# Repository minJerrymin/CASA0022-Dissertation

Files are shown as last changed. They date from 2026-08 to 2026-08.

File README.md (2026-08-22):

# Design and Deployment of a Solar-Powered LoRaWAN Air Quality Monitoring System

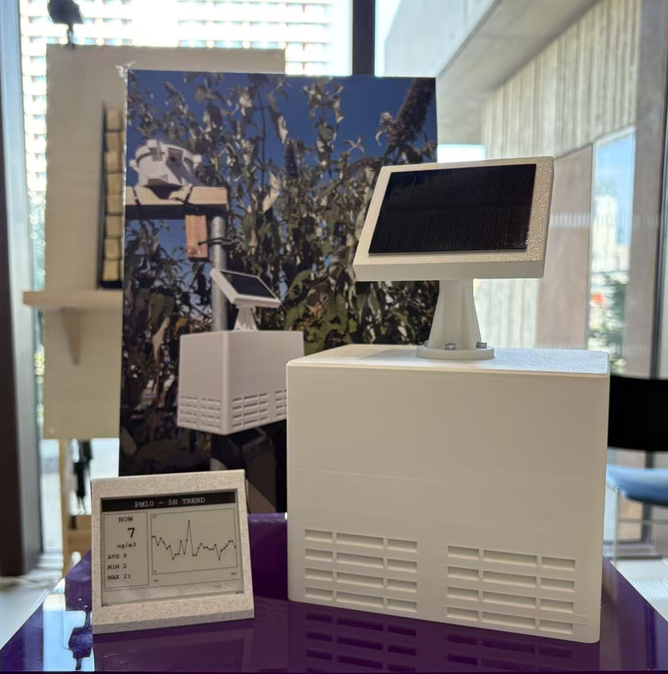
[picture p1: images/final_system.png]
Completed solar-powered sensing system


## Project overview

This project develops and deploys a solar-powered LoRaWAN air-quality sensing node to explore whether low-cost distributed sensing can contribute to denser urban monitoring where mains power is unavailable. It combines particulate and environmental sensing, low-power operation, cloud data storage and an indoor e-paper display.

The prototype demonstrates conditional viability rather than reference-grade performance. Its operation depends on adequate LoRaWAN coverage and available solar energy, and the external comparison sites were not co-located with the sensing node.

## System architecture

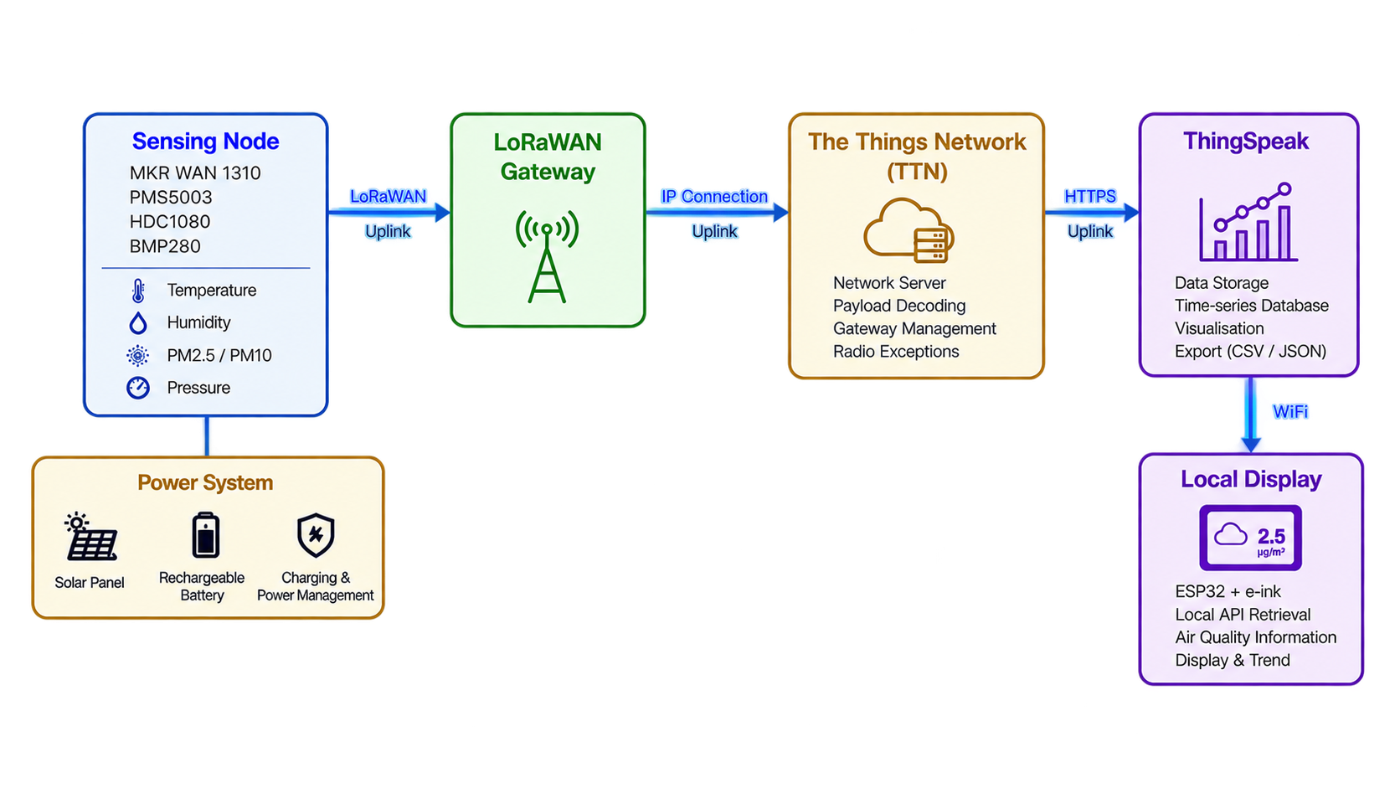
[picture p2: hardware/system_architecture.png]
Final system architecture and data pathway


The deployed data pathway is:

**Sensing node → LoRaWAN gateway → The Things Network (TTN) → ThingSpeak → Wi-Fi → local ESP32 + e-paper display**

The solar-powered outdoor node sends unconfirmed LoRaWAN uplinks through a gateway to The Things Network. Decoded measurements are forwarded to ThingSpeak. The indoor display separately retrieves the ThingSpeak channel over Wi-Fi; it does not receive data directly from TTN.

## Hardware

The sensing node uses an Arduino MKR WAN 1310 with an HDC1080, BMP280 and Plantower PMS5003. A 1 W solar panel and three-cell 3.6 V nominal NiMH battery pack connect through the Battery Charging Board, whose LOAD/OUTPUT supplies the MKR battery connector. MKR VIN is not used.

The MKR 3.3 V rail powers the HDC1080, BMP280 and Pololu S7V7F5 input. The Pololu output supplies 5 V to the PMS5003; MKR D5 controls SHDN. Two 100 µF capacitors stabilise the regulator input and output rails. All grounds are common.

The final physical UART arrangement is intentional: **MKR TX1 → PMS TX** and **MKR RX1 → PMS RX**.

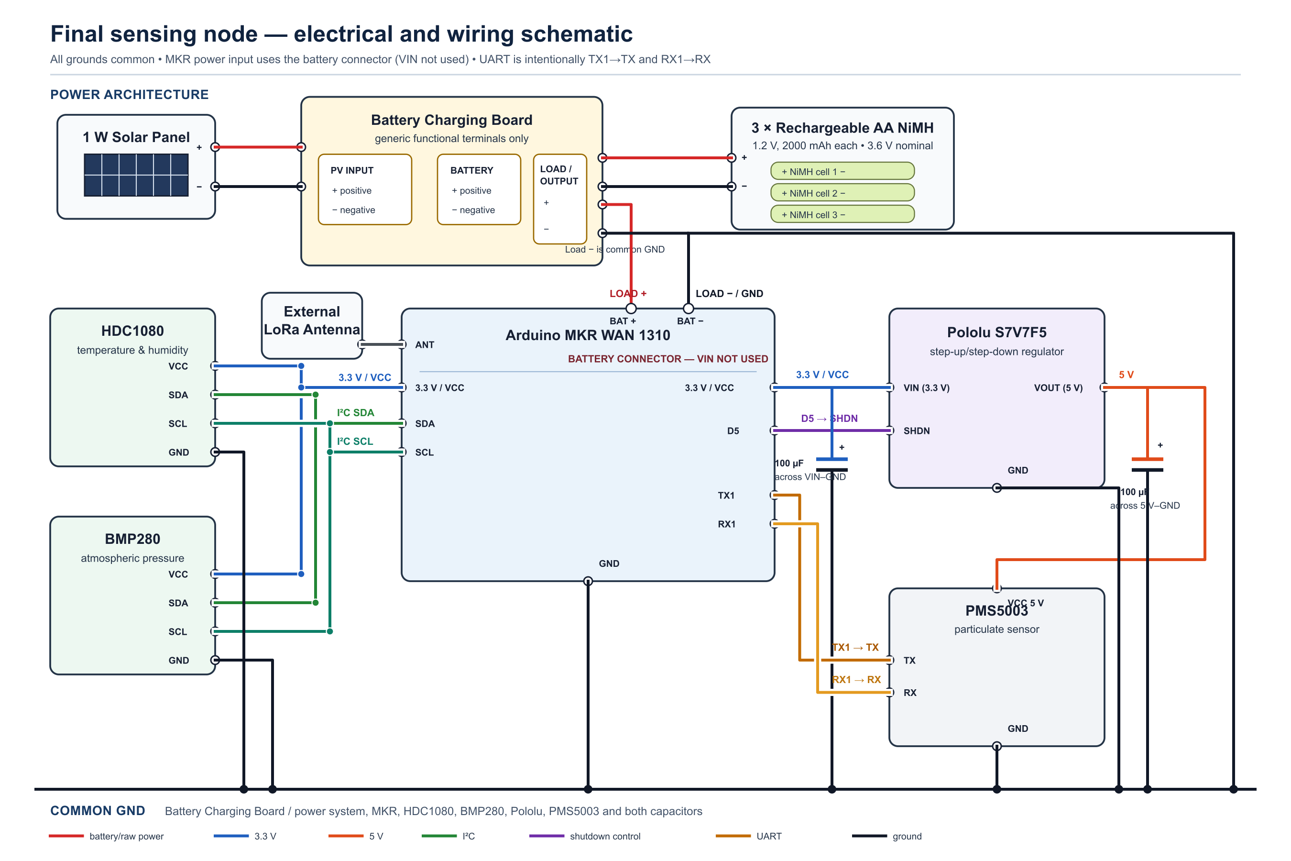
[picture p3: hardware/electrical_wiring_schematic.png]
Detailed electrical wiring schematic


See the concise [bill of materials](hardware/BOM.md).

## Firmware

- [`firmware/sensing_node/`](firmware/sensing_node/) — deployed MKR WAN 1310 sensing-node firmware.
- [`firmware/display/`](firmware/display/) — deployed FireBeetle 2 ESP32-E e-paper display firmware.
- [`firmware/diagnostics/`](firmware/diagnostics/) — standalone PMS5003 diagnostic utility, **not** the deployed sensing-node firmware.

Real TTN, Wi-Fi and ThingSpeak credentials are not included. For each deployed sketch, copy `arduino_secrets.example.h` to `arduino_secrets.h`, replace the placeholders locally, and keep that local file untracked.

The display firmware retains `WiFiClientSecure.setInsecure()` to reproduce the prototype. This disables TLS certificate verification and is a known prototype security limitation; a production deployment should validate the server certificate.

## LoRaWAN payload

The MKR WAN 1310 uses OTAA in the EU868 region and sends an unconfirmed 10-byte uplink on FPort 2.

| Bytes | Measurement | Encoding |
|---:|---|---|
| 0–1 | Temperature | signed int16, °C × 100 |
| 2–3 | Relative humidity | uint16, % × 100 |
| 4–5 | PM2.5 | uint16, µg/m³ |
| 6–7 | PM10 | uint16, µg/m³ |
| 8–9 | Atmospheric pressure | uint16, hPa × 10 |

Invalid PMS readings use the uint16 sentinel `65535`. The matching [TTN uplink decoder](ttn/uplink_decoder.js) exposes both descriptive names and ThingSpeak `field1`–`field5` values; it does not add a payload flag.

## Power management

Each cycle is 10 minutes. The PMS5003/regulator branch is enabled for a 30-second sensor warm-up and switched off during sleep. The measured whole-system active current was approximately 89.6 mA for an active period of about 37–40 seconds; sleep current was approximately 137 µA. This gives an estimated cycle-average current of approximately 6.13 mA.

These measurements support the feasibility of the low-power approach, but they do not establish guaranteed year-round solar autonomy.

## Deployment

The system was deployed at the UCL One Pool Street Roof Garden.

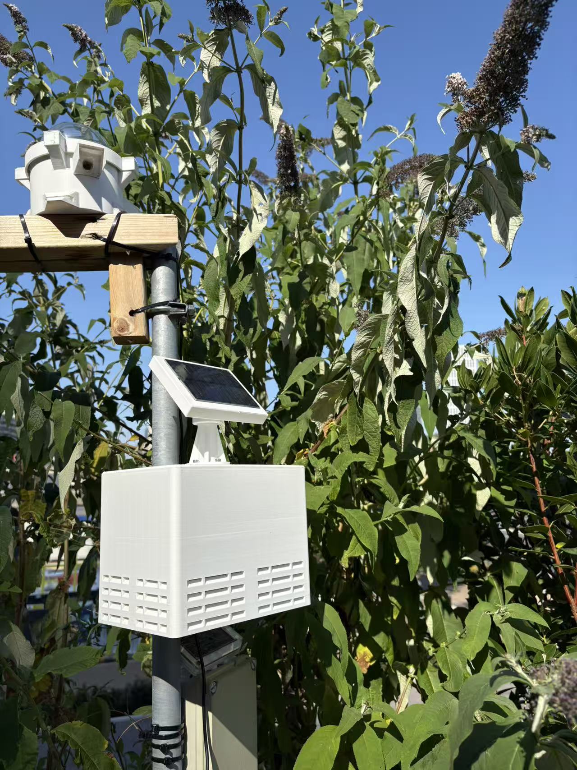
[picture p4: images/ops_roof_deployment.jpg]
Sensing node deployed at the UCL One Pool Street Roof Garden


## Evaluation and results

- ThingSpeak contains 4,961 complete records over a 38.42-day monitoring span. The median interval was 10.00 minutes, 98.79% of intervals were between 9.5 and 10.5 minutes, and the longest continuous period without a gap over one hour was approximately 34.66 days. Four early long gaps occurred during debugging, power-off and system reconfiguration, before the stable deployment period.
- The final TTN export contains 318 uplinks over approximately 2.21 days, with a 10.00-minute median interval, one absent frame counter and 994 total gateway receptions.
- Temporal comparison showed strong agreement for temperature, relative humidity and pressure; PM2.5 agreement was moderate and PM10 agreement was weak.
- The PMS5003 reported identical PM2.5 and PM10 values in 4,903 of 4,961 records (98.83%), an important limitation of this prototype dataset.

Because the Weather Underground and London Air Quality Network stations were not co-located with the project node, these results are temporal comparisons rather than formal calibration. They do not demonstrate reference-grade accuracy or validated PM10 performance.

## E-paper display

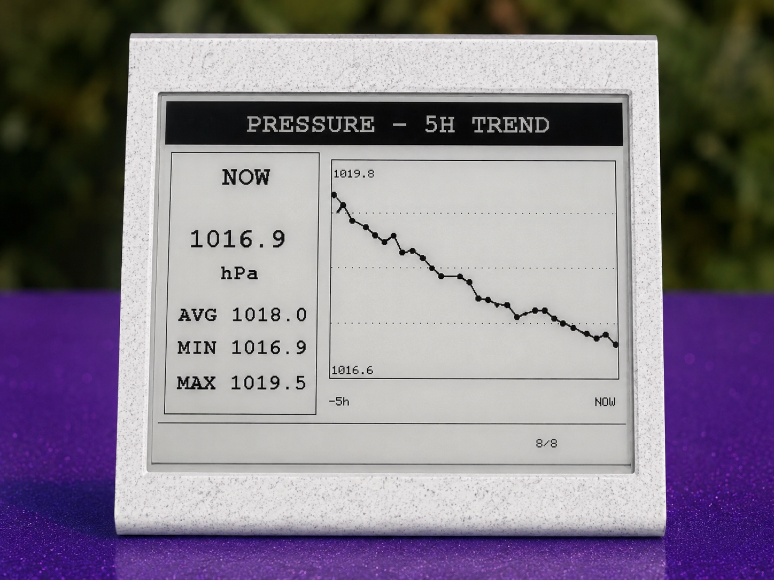
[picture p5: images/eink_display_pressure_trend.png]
Pressure five-hour trend on page 8 of the e-paper display


The indoor FireBeetle 2 ESP32-E display retrieves the latest ThingSpeak entry approximately every 60 seconds. When a new entry is detected it downloads 30 ten-minute samples, providing approximately five hours of history. Eight pages are shown for 20 seconds each (160 seconds per carousel); after three complete cycles, the firmware returns to a full-refresh summary page.

## CAD

The repository includes the author's editable Fusion 360 source and printable STL for the [indoor display enclosure](hardware/cad/display_enclosure/). These files are not sensing-node enclosure CAD.

The outdoor sensing enclosure's concept and functional requirements were developed through discussion involving the project author and Simon. Simon completed the detailed CAD design and 3D printing; his sensing-enclosure CAD is not published here.

## Data and analysis

- [Data documentation](data/README.md)
- [Analysis method and reproduction instructions](analysis/README.md)

The final ThingSpeak observations and metadata-minimised TTN analytical CSV are public. Raw Weather Underground and LAQN comparison files remain local because redistribution rights have not been assumed.

## Repository structure

```text
.
├── analysis/                  # Reproducible final calculations
├── data/                      # Public project and clean TTN data
├── firmware/
│   ├── sensing_node/          # Deployed outdoor-node firmware
│   ├── display/               # Deployed e-paper firmware
│   └── diagnostics/           # PMS5003 diagnostic utility
├── hardware/
│   └── cad/display_enclosure/ # Author's indoor-display CAD
├── images/                    # Selected final project images
├── ttn/                       # 10-byte uplink decoder
├── index.html                 # GitHub Pages exhibition page
└── README.md
```

## Dissertation context

This repository accompanies the CASA0022 MSc Connected Environments dissertation at University College London. It provides the technical implementation, selected data and reproducible final analysis; the dissertation PDF is not included.

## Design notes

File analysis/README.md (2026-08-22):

# Final analysis

`final_analysis.py` reconstructs the final Chapter 4 calculations from the supplied project data and local comparison inputs. It calculates each result from the observations; dissertation target values are used only for the printed validation comparison.

## Requirements

- Python 3.10 or later
- Packages listed in `requirements.txt` (`pandas` and `numpy`)

Install and run from the repository root:

```bash
python -m pip install -r analysis/requirements.txt
python analysis/final_analysis.py
```

To regenerate the public TTN analytical CSV from the local raw export:

```bash
python analysis/final_analysis.py --write-clean-ttn
```

## Inputs

| Input | Default path | Public? | Purpose |
|---|---|---:|---|
| Project sensing data | `data/project_sensing_data.csv` | Yes | Operational statistics, hourly project means and PMS consistency |
| Clean TTN data | `data/ttn_uplinks_clean.csv` | Yes | Public fallback for TTN statistics |
| Raw TTN export | `../ttn_uplinks_30days.jsonl` | No | Local regeneration of the clean TTN CSV |
| Weather Underground JSON | `../wunderground_20260801_20260816.json` | No | Temperature, humidity and pressure comparison |
| LAQN CSV | `../Londonair PM DATA.csv` | No | PM2.5 and PM10 comparison |

The three local-only paths assume the supplied source files remain beside the repository. Command-line options can point to equivalent files elsewhere. If the external comparison files are absent, the script still runs the operational, TTN and PMS consistency analyses and reports that the comparisons were skipped.

## Method

ThingSpeak `created_at` values and TTN timestamps are parsed as UTC and sorted chronologically. Consecutive intervals are calculated directly. A stable segment ends whenever the next interval exceeds one hour; the longest segment is the largest elapsed time between its first and last records.

For external comparisons, project observations are converted from UTC to `Europe/London`, floored to the local hour and averaged. Weather Underground observations use the supplied `obsTimeLocal` hour for station ILONDO932. Temperature uses `tempAvg`, humidity uses `humidityAvg`, and pressure is `(pressureMax + pressureMin) / 2`.

LAQN `ReadingDateTime` is parsed day-first as local clock time. Hourly project PM means are matched by local hour to site TH5 (Tower Hamlets, Victoria Park). Missing external values are excluded pairwise, which produces 791 PM2.5 pairs and 779 PM10 pairs in the supplied files.

Pearson's `r` is calculated from each matched pair of numeric series. Mean difference always means `project − external source`. The sites were not co-located, so these are temporal comparisons rather than a formal calibration.

## Outputs

The script prints a concise `metric | reproduced | expected | status` table. `PASS` means the reconstructed value falls within a small, explicitly defined rounding tolerance; `INFO` identifies a useful metric for which the dissertation specification did not state an expected value.

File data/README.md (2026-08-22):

# Data

## `project_sensing_data.csv`

This is the final sensing dataset exported from the project's ThingSpeak channel. It contains 4,961 records from 9 July to 17 August 2026. All five measurement fields are populated in every record.

| Column | Measurement | Unit |
|---|---|---|
| `field1` | Temperature | °C |
| `field2` | Relative humidity | % |
| `field3` | PM2.5 | µg/m³ |
| `field4` | PM10 | µg/m³ |
| `field5` | Atmospheric pressure | hPa |

The observations are unchanged from the final export; only the filename has been made descriptive.

## `ttn_uplinks_clean.csv`

This public analytical dataset contains 318 final TTN uplinks from approximately 15–17 August 2026. It retains the timestamp, frame counter, FPort, decoded measurements and number of gateway receptions for each uplink.

The local raw JSONL export was not published. Device and application identifiers, EUIs and addresses, gateway identifiers and locations, radio metadata, correlation identifiers, raw binary payloads and other network metadata were removed because they are unnecessary for the reported analysis.

## External comparison data

Raw third-party files are intentionally not redistributed. To reproduce the complete comparison, obtain equivalent exports in the formats described in [the analysis documentation](../analysis/README.md):

- Weather Underground personal weather station ILONDO932, 1–16 August 2026, for temperature, relative humidity and pressure.
- London Air Quality Network site TH5 — Tower Hamlets, Victoria Park, for PM2.5 and PM10.

These external sites were not co-located with the project sensing node. The comparison therefore assesses temporal agreement rather than formal sensor calibration.

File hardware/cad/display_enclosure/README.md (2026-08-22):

# Indoor display enclosure

These files are the author's enclosure design for the indoor e-paper display, created in Autodesk Fusion 360 for the DFRobot FireBeetle 2 ESP32-E and 4.2-inch e-paper display.

- `display_enclosure.f3d` is the editable Fusion 360 source.
- `display_enclosure.stl` is the printable export.

This is not the outdoor sensing-node enclosure. The sensing enclosure's concept and functional requirements were developed through discussion involving the project author and Simon; Simon completed its detailed CAD design and 3D printing. Simon's CAD files are not included here.

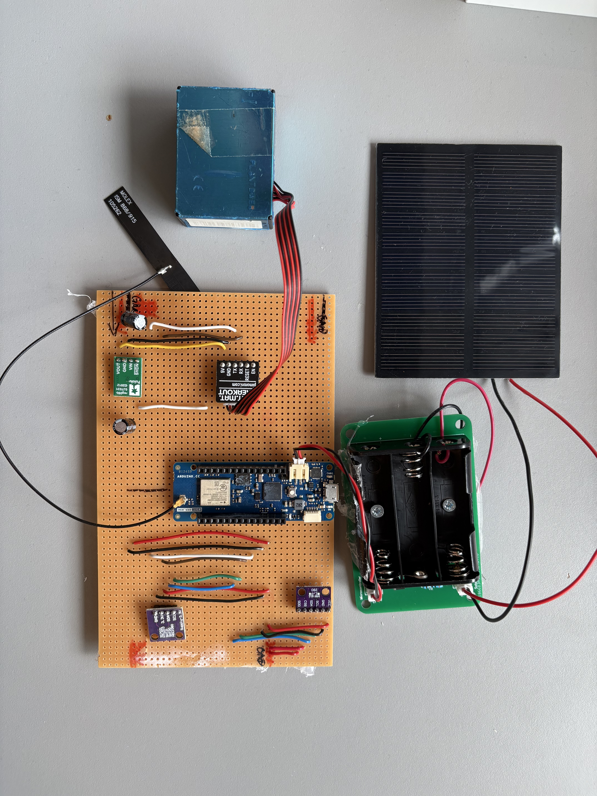
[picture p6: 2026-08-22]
images/sensing_node_internal_hardware.jpg

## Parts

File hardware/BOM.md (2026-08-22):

# Bill of materials

## Outdoor sensing node

| Item | Quantity / specification |
|---|---|
| Arduino MKR WAN 1310 | 1 |
| Plantower PMS5003 | 1 |
| HDC1080 temperature/humidity module | 1 |
| BMP280 pressure module | 1 |
| Pololu S7V7F5 5 V step-up/step-down regulator | 1 |
| Solar panel | 1 W |
| Rechargeable AA NiMH cells | 3 × 1.2 V, 2000 mAh |
| Battery Charging Board | 1 |
| Capacitors | 2 × 100 µF |
| External LoRa antenna | 1 |
| Stripboard and wiring | As required |
| 3D-printed sensing enclosure | 1 |

The Battery Charging Board LOAD/OUTPUT supplies the MKR WAN 1310 through its battery connector; MKR VIN is not used. The Pololu regulator supplies 5 V to the PMS5003 and its SHDN input is controlled by MKR D5.

The sensing enclosure's concept and functional requirements were developed through discussion involving the project author and Simon. Simon completed the detailed CAD design and 3D printing; those CAD files are not included.

## Indoor display

| Item | Quantity / specification |
|---|---|
| DFRobot FireBeetle 2 ESP32-E | 1 |
| 4.2-inch e-paper display | 1 |
| 3D-printed display enclosure | 1 |

The included [display enclosure CAD](cad/display_enclosure/) was designed by the project author and is distinct from the sensing enclosure.

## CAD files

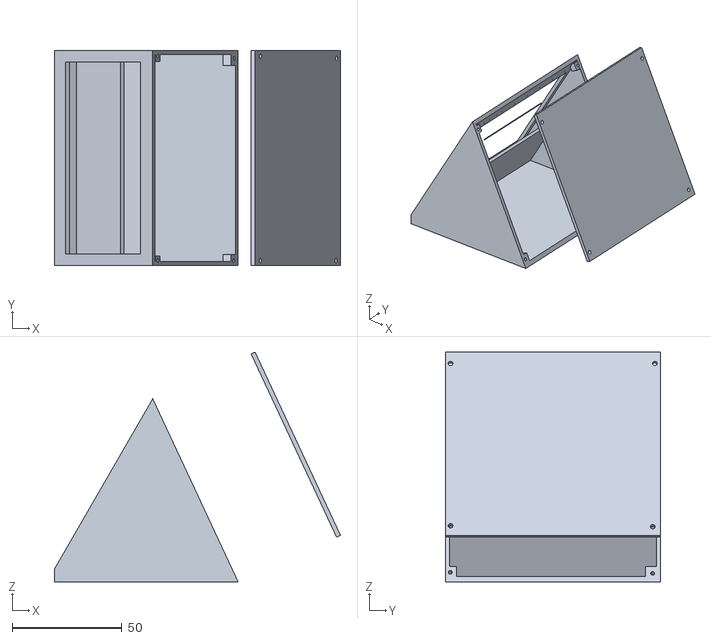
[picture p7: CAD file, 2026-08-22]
hardware/cad/display_enclosure/display_enclosure.stl
130.2 x 98.0 x 104.6

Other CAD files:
hardware/cad/display_enclosure/display_enclosure.f3d

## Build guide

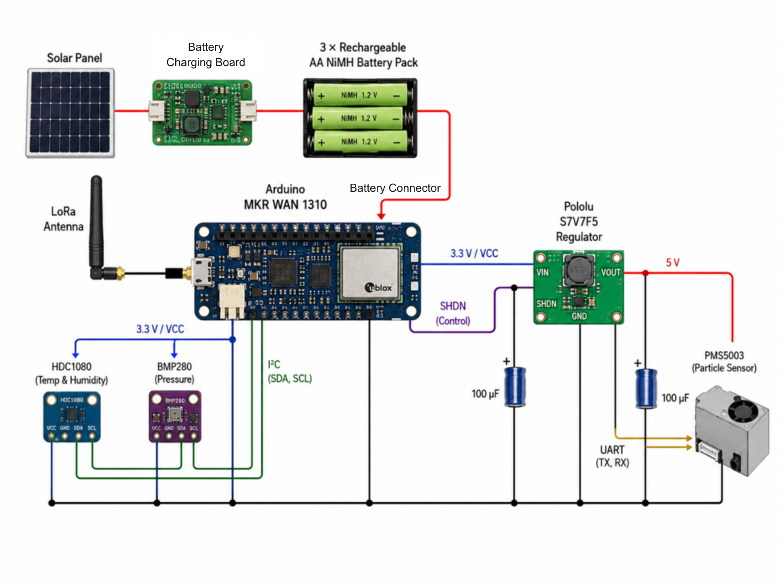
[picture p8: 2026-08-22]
hardware/system_wiring_architecture.png

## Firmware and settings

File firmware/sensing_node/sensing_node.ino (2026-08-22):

#include <MKRWAN.h>
#include <ArduinoLowPower.h>
#include <Wire.h>
#include <math.h>
#include <Adafruit_BMP280.h>
#include "arduino_secrets.h"

LoRaModem modem;
Adafruit_BMP280 bmp280;
String appEui = SECRET_TTN_JOIN_EUI;
String appKey = SECRET_TTN_APP_KEY;

// ================= Timing =================
const unsigned long CYCLE_MS = 600000UL;       // 10 minutes duty cycle
const unsigned long PMS_WARMUP_MS = 30000UL;
const unsigned long PMS_READ_TIMEOUT_MS = 8000UL;

// ================= Pins =================

const int PMS_BOOST_SHDN_PIN = 5;

// Serial1 pins on the MKR WAN 1310. The final prototype intentionally wires
// MKR TX1 to PMS TX and MKR RX1 to PMS RX; no crossover is used.
#ifndef PIN_SERIAL1_RX
#define PIN_SERIAL1_RX 13
#endif

#ifndef PIN_SERIAL1_TX
#define PIN_SERIAL1_TX 14
#endif


const uint8_t HDC1080_ADDR = 0x40;
const uint8_t BMP280_ADDR_PRIMARY = 0x76;
const uint8_t BMP280_ADDR_SECONDARY = 0x77;


const uint8_t PMS_WAKE_CMD[]  = {0x42, 0x4D, 0xE4, 0x00, 0x01, 0x01, 0x74};
const uint8_t PMS_SLEEP_CMD[] = {0x42, 0x4D, 0xE4, 0x00, 0x00, 0x01, 0x73};

struct PMSData {
  uint16_t pm25;
  uint16_t pm10;
  bool valid;
};

void setup() {
  // Serial output is disabled during deployed low-power operation.
  delay(15000);
#if defined(USBCON)
  USBDevice.detach();
#endif

  // Keep LED off
  pinMode(LED_BUILTIN, OUTPUT);
  digitalWrite(LED_BUILTIN, LOW);

  // Important: disable Pololu immediately after boot
  pinMode(PMS_BOOST_SHDN_PIN, OUTPUT);
  digitalWrite(PMS_BOOST_SHDN_PIN, LOW);   // Pololu off, PMS physically off
  //digitalWrite(PMS_BOOST_SHDN_PIN, HIGH);
  //delay(3000);

  isolatePMSPins();
  sleepI2CBus();

  if (!modem.begin(EU868)) {
    while (1) {
      LowPower.deepSleep(60000);
    }
  }

  joinTTN();

  modem.setPort(2);
  modem.minPollInterval(60);

  modem.sleep(true);
}


void loop() {
  unsigned long cycleStart = millis();

  // Wake LoRa modem
  modem.sleep(false);
  delay(500);

  // Power on PMS 5V branch
  powerPMSOn();

  // PMS warm-up after physical power-on
  delay(PMS_WARMUP_MS);

  float temperature = NAN;
  float humidity = NAN;
  bool hdcOK = readHDC1080(temperature, humidity);

  float pressure_hPa = NAN;
  bool bmpOK = readBMP280Pressure(pressure_hPa);

  PMSData pms = readPMS5003_PM25_PM10(PMS_READ_TIMEOUT_MS);

  if (!hdcOK) {
    temperature = 0;
    humidity = 0;
  }

  if (!pms.valid) {
    pms.pm25 = 65535;
    pms.pm10 = 65535;
  }

  if (!bmpOK) {
    pressure_hPa = 6553.5;  // Encoded as 65535 after x10; invalid sentinel
  }

  sendPayload_PM25_PM10_BMP280(temperature, humidity, pms.pm25, pms.pm10, pressure_hPa);

  // Give LoRa modem time to settle after uplink
  delay(3000);

  // Power down everything possible
  powerPMSOff();
  sleepI2CBus();

  modem.sleep(true);

#if defined(USBCON)
  USBDevice.detach();
#endif

  unsigned long activeTime = millis() - cycleStart;
  unsigned long sleepTime = 10000UL;

  if (activeTime < CYCLE_MS) {
    sleepTime = CYCLE_MS - activeTime;
  }

  LowPower.deepSleep(sleepTime);
}

// ================= TTN =================

void joinTTN() {
  int connected = 0;

  while (!connected) {
    modem.sleep(false);
    delay(500);

    connected = modem.joinOTAA(appEui, appKey);

    if (!connected) {
      modem.sleep(true);

#if defined(USBCON)
      USBDevice.detach();
#endif

      LowPower.deepSleep(60000);
    }
  }
}

void sendPayload_PM25_PM10_BMP280(float temperature, float humidity, uint16_t pm25, uint16_t pm10, float pressure_hPa) {
  int16_t tempInt = (int16_t)round(temperature * 100.0);
  uint16_t humInt = (uint16_t)round(humidity * 100.0);
  uint16_t pressureInt = (uint16_t)round(pressure_hPa * 10.0);  // hPa x10

  uint8_t payload[10];

  payload[0] = highByte(tempInt);
  payload[1] = lowByte(tempInt);

  payload[2] = highByte(humInt);
  payload[3] = lowByte(humInt);

  payload[4] = highByte(pm25);
  payload[5] = lowByte(pm25);

  payload[6] = highByte(pm10);
  payload[7] = lowByte(pm10);

  payload[8] = highByte(pressureInt);
  payload[9] = lowByte(pressureInt);

  modem.beginPacket();
  modem.write(payload, sizeof(payload));
  modem.endPacket(false);
}

// ================= PMS5003 power control =================

void powerPMSOn() {
  // Enable Pololu 5V boost
  pinMode(PMS_BOOST_SHDN_PIN, OUTPUT);
  digitalWrite(PMS_BOOST_SHDN_PIN, HIGH);
  delay(1000);

  Serial1.begin(9600);
  delay(500);

  // Serial1.write(PMS_WAKE_CMD, sizeof(PMS_WAKE_CMD));
  // Serial1.flush();
  // delay(500);

  flushPMS();
}

void powerPMSOff() {
  // Optional graceful PMS sleep command before power cut
  Serial1.write(PMS_SLEEP_CMD, sizeof(PMS_SLEEP_CMD));
  Serial1.flush();
  delay(300);

  Serial1.end();

  // Avoid back-powering the unpowered PMS through UART pins
  isolatePMSPins();

  // Disable Pololu 5V boost: PMS physically off
  digitalWrite(PMS_BOOST_SHDN_PIN, LOW);
}

void isolatePMSPins() {
  // Do not use INPUT_PULLUP here, because PMS is unpowered during sleep.
  // Pullups may back-power the PMS through protection paths.
  pinMode(PIN_SERIAL1_RX, INPUT);
  pinMode(PIN_SERIAL1_TX, INPUT);
}

void flushPMS() {
  while (Serial1.available()) {
    Serial1.read();
  }
}

PMSData readPMS5003_PM25_PM10(unsigned long timeoutMs) {
  PMSData data;
  data.pm25 = 0;
  data.pm10 = 0;
  data.valid = false;

  uint8_t frame[32];
  unsigned long start = millis();

  while (millis() - start < timeoutMs) {
    if (Serial1.available()) {
      uint8_t b = Serial1.read();

      if (b != 0x42) {
        continue;
      }

      unsigned long waitStart = millis();
      while (!Serial1.available() && millis() - waitStart < 100) {}

      if (!Serial1.available()) {
        continue;
      }

      if (Serial1.read() != 0x4D) {
        continue;
      }

      frame[0] = 0x42;
      frame[1] = 0x4D;

      int index = 2;
      unsigned long frameStart = millis();

      while (index < 32 && millis() - frameStart < 1000) {
        if (Serial1.available()) {
          frame[index++] = Serial1.read();
        }
      }

      if (index != 32) {
        continue;
      }

      uint16_t sum = 0;
      for (int i = 0; i < 30; i++) {
        sum += frame[i];
      }

      uint16_t checksum = ((uint16_t)frame[30] << 8) | frame[31];

      if (sum != checksum) {
        continue;
      }

      uint16_t frameLen = ((uint16_t)frame[2] << 8) | frame[3];

      if (frameLen != 28) {
        continue;
      }

      // Atmospheric PM2.5 and PM10
      data.pm25 = ((uint16_t)frame[12] << 8) | frame[13];
      data.pm10 = ((uint16_t)frame[14] << 8) | frame[15];
      data.valid = true;
      return data;
    }
  }

  return data;
}


// ================= BMP280 =================

bool beginBMP280() {
  if (bmp280.begin(BMP280_ADDR_PRIMARY)) {
    return true;
  }

  if (bmp280.begin(BMP280_ADDR_SECONDARY)) {
    return true;
  }

  return false;
}

bool readBMP280Pressure(float &pressure_hPa) {
  Wire.begin();
  delay(10);

  if (!beginBMP280()) {
    sleepI2CBus();
    return false;
  }

  bmp280.setSampling(
    Adafruit_BMP280::MODE_FORCED,
    Adafruit_BMP280::SAMPLING_X1,
    Adafruit_BMP280::SAMPLING_X1,
    Adafruit_BMP280::FILTER_OFF,
    Adafruit_BMP280::STANDBY_MS_1
  );

  if (!bmp280.takeForcedMeasurement()) {
    sleepI2CBus();
    return false;
  }

  pressure_hPa = bmp280.readPressure() / 100.0;

  sleepI2CBus();
  return true;
}

// ================= HDC1080 =================

void setupHDC1080() {
  Wire.beginTransmission(HDC1080_ADDR);
  Wire.write(0x02);
  Wire.write(0x10);
  Wire.write(0x00);
  Wire.endTransmission();
  delay(20);
}

bool readHDC1080(float &temperature, float &humidity) {
  Wire.begin();
  delay(10);
  setupHDC1080();

  Wire.beginTransmission(HDC1080_ADDR);
  Wire.write(0x00);

  if (Wire.endTransmission() != 0) {
    sleepI2CBus();
    return false;
  }

  delay(20);

  Wire.requestFrom(HDC1080_ADDR, (uint8_t)4);

  if (Wire.available() < 4) {
    sleepI2CBus();
    return false;
  }

  uint16_t rawT = ((uint16_t)Wire.read() << 8) | Wire.read();
  uint16_t rawH = ((uint16_t)Wire.read() << 8) | Wire.read();

  temperature = ((float)rawT / 65536.0) * 165.0 - 40.0;
  humidity = ((float)rawH / 65536.0) * 100.0;

  if (humidity < 0) humidity = 0;
  if (humidity > 100) humidity = 100;

  sleepI2CBus();
  return true;
}

void sleepI2CBus() {
  Wire.end();

  // HDC1080 and BMP280 remain powered by MKR 3.3V.
  // Keep I2C lines in stable high state for low leakage.
  pinMode(SDA, INPUT_PULLUP);
  pinMode(SCL, INPUT_PULLUP);
}

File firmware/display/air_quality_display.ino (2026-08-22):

#include <WiFi.h>
#include <HTTPClient.h>
#include <WiFiClientSecure.h>
#include <ArduinoJson.h>
#include <SPI.h>
#include <GxEPD2_BW.h>
#include <Fonts/FreeMonoBold24pt7b.h>
#include <Fonts/FreeMonoBold12pt7b.h>
#include <Fonts/FreeMonoBold9pt7b.h>
#include <math.h>
#include <time.h>
#include "arduino_secrets.h"

// =====================================================
// Network and ThingSpeak settings
// =====================================================

const char* WIFI_SSID = SECRET_WIFI_SSID;
const char* WIFI_PASSWORD = SECRET_WIFI_PASSWORD;

const char* CHANNEL_ID = SECRET_THINGSPEAK_CHANNEL_ID;
const char* READ_API_KEY = SECRET_THINGSPEAK_READ_API_KEY;

// Polling the lightweight last-entry endpoint does not refresh the display.
// A full history request is made only when a new entry ID is detected.
const unsigned long FETCH_INTERVAL_MS = 60UL * 1000UL;

// Expected sensor cadence is one sample every 10 minutes.
// Thirty samples therefore cover approximately five hours.
const uint8_t HISTORY_CAPACITY = 30;

// Eight pages at 20 seconds each give 160 seconds per carousel cycle.
// After three complete cycles, retain the summary page with a full refresh.
const uint8_t CAROUSEL_CYCLES = 3;

unsigned long lastFetchTime = 0;


// =====================================================
// Waveshare Pico-ePaper-4.2 V2 connections
// =====================================================

#define EPD_CS    13  // FireBeetle D7
#define EPD_DC    25  // FireBeetle D2
#define EPD_RST   26  // FireBeetle D3
#define EPD_BUSY  34  // FireBeetle A2

GxEPD2_BW<GxEPD2_420_GDEY042T81,
          GxEPD2_420_GDEY042T81::HEIGHT> display(
  GxEPD2_420_GDEY042T81(
    EPD_CS,
    EPD_DC,
    EPD_RST,
    EPD_BUSY
  )
);


// =====================================================
// Data models
// =====================================================

struct AirQualityData {
  float temperature;
  float humidity;
  float pm25;
  float pm10;
  float pressure;
  String createdAt;
  int entryID;
};

enum Metric : uint8_t {
  METRIC_TEMPERATURE = 0,
  METRIC_HUMIDITY,
  METRIC_PM25,
  METRIC_PM10,
  METRIC_PRESSURE,
  METRIC_COUNT
};

struct HistoryData {
  float values[METRIC_COUNT][HISTORY_CAPACITY];
  uint8_t count;
  String firstCreatedAt;
  String lastCreatedAt;
};

AirQualityData latestData;
HistoryData historyData;
int lastLoadedEntryID = -1;


// =====================================================
// Carousel state
// =====================================================

enum DisplayPage : uint8_t {
  PAGE_SUMMARY = 0,
  PAGE_COMFORT,
  PAGE_AIR_QUALITY,
  PAGE_TEMPERATURE_TREND,
  PAGE_HUMIDITY_TREND,
  PAGE_PM25_TREND,
  PAGE_PM10_TREND,
  PAGE_PRESSURE_TREND,
  PAGE_COUNT
};

const unsigned long PAGE_DURATION_MS[PAGE_COUNT] = {
  20000UL,
  20000UL,
  20000UL,
  20000UL,
  20000UL,
  20000UL,
  20000UL,
  20000UL,
};

bool carouselActive = false;
uint8_t currentPage = PAGE_SUMMARY;
uint8_t completedCycles = 0;
unsigned long pageShownAt = 0;

bool displayEverInitialised = false;
bool displayIsAwake = false;


// =====================================================
// Wi-Fi connection
// =====================================================

bool connectWiFi() {
  if (WiFi.status() == WL_CONNECTED) {
    return true;
  }

  Serial.println();
  Serial.print("Connecting to Wi-Fi: ");
  Serial.println(WIFI_SSID);

  WiFi.mode(WIFI_STA);
  WiFi.begin(WIFI_SSID, WIFI_PASSWORD);

  unsigned long startTime = millis();

  while (WiFi.status() != WL_CONNECTED &&
         millis() - startTime < 20000UL) {
    delay(500);
    Serial.print(".");
  }

  Serial.println();

  if (WiFi.status() == WL_CONNECTED) {
    Serial.println("Wi-Fi connected.");
    Serial.print("ESP32 IP address: ");
    Serial.println(WiFi.localIP());
    Serial.print("Wi-Fi RSSI: ");
    Serial.print(WiFi.RSSI());
    Serial.println(" dBm");
    return true;
  }

  Serial.println("Wi-Fi connection failed.");
  return false;
}


// =====================================================
// Generic helpers
// =====================================================

float jsonFieldToFloat(JsonVariantConst value) {
  if (value.isNull()) {
    return NAN;
  }

  const char* text = value.as<const char*>();
  if (text == nullptr || text[0] == '\0') {
    return NAN;
  }

  return strtof(text, nullptr);
}


String formatThingSpeakTime(const String& isoTime) {
  if (isoTime.length() < 19) return "unknown";

  struct tm utcTime = {};
  int year, month, day, hour, minute, second;

  if (sscanf(isoTime.c_str(), "%d-%d-%dT%d:%d:%d",
             &year, &month, &day, &hour, &minute, &second) != 6) {
    return "unknown";
  }

  utcTime.tm_year = year - 1900;
  utcTime.tm_mon  = month - 1;
  utcTime.tm_mday = day;
  utcTime.tm_hour = hour;
  utcTime.tm_min  = minute;
  utcTime.tm_sec  = second;

  utcTime.tm_isdst = 0;

  setenv("TZ", "UTC0", 1);
  tzset();
  time_t epoch = mktime(&utcTime);

  setenv("TZ", "GMT0BST,M3.5.0/1,M10.5.0/2", 1);
  tzset();

  struct tm ukTime;
  localtime_r(&epoch, &ukTime);



  char buffer[24];
  strftime(buffer, sizeof(buffer), "%Y-%m-%d %H:%M %Z", &ukTime);
  return String(buffer);
}


float currentMetricValue(Metric metric) {
  switch (metric) {
    case METRIC_TEMPERATURE: return latestData.temperature;
    case METRIC_HUMIDITY:    return latestData.humidity;
    case METRIC_PM25:        return latestData.pm25;
    case METRIC_PM10:        return latestData.pm10;
    case METRIC_PRESSURE:    return latestData.pressure;
    default:                 return NAN;
  }
}


const char* metricName(Metric metric) {
  switch (metric) {
    case METRIC_TEMPERATURE: return "TEMPERATURE";
    case METRIC_HUMIDITY:    return "HUMIDITY";
    case METRIC_PM25:        return "PM2.5";
    case METRIC_PM10:        return "PM10";
    case METRIC_PRESSURE:    return "PRESSURE";
    default:                 return "UNKNOWN";
  }
}


const char* metricUnit(Metric metric) {
  switch (metric) {
    case METRIC_TEMPERATURE: return "C";
    case METRIC_HUMIDITY:    return "%";
    case METRIC_PM25:
    case METRIC_PM10:        return "ug/m3";
    case METRIC_PRESSURE:    return "hPa";
    default:                 return "";
  }
}


unsigned int metricDecimals(Metric metric) {
  return (metric == METRIC_PM25 || metric == METRIC_PM10) ? 0 : 1;
}


float metricMinimumSpan(Metric metric) {
  switch (metric) {
    case METRIC_TEMPERATURE: return 2.0f;
    case METRIC_HUMIDITY:    return 5.0f;
    case METRIC_PM25:
    case METRIC_PM10:        return 5.0f;
    case METRIC_PRESSURE:    return 2.0f;
    default:                 return 1.0f;
  }
}


// =====================================================
// Display text helpers
// =====================================================
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
